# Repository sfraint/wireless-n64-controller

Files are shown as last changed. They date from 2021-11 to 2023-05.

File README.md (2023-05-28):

# wireless-n64-controller
This project and its documentation is a Work-In-Progress. I'm still working on writing everything down and working out kinks in the design files and prototypes.

**The idea is to publish the design files and software used to upgrade an OEM or cheap, wired N64 controller to a wireless, Bluetooth controller**. Hopefully these published files can assist others in completing similar projects.

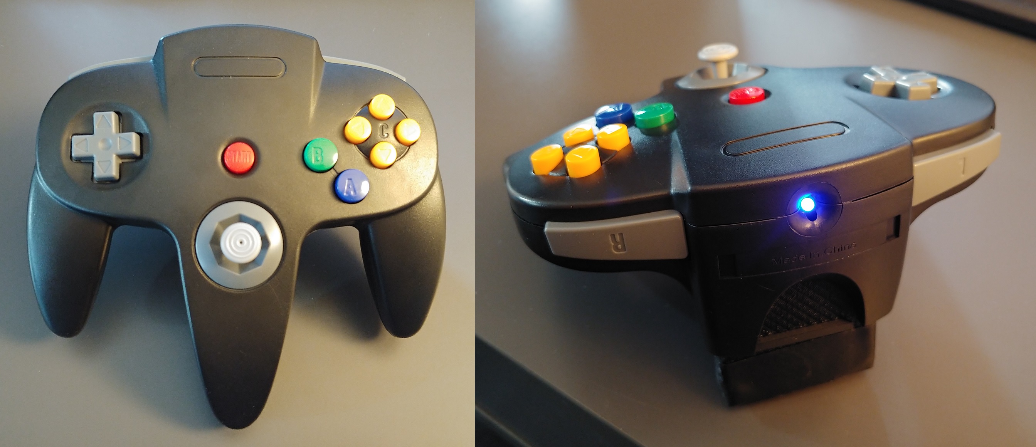
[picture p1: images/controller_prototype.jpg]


## Motivation
When this project was started, no original-form-factor bluetooth N64 wireless controllers were available for purchase. There were some two-handle controllers, inspired by N64 original controllers, but none with the original three-handle setup.

The main goal of this project was to upgrade an existing OEM or cheap three-handle N64 wired controller to use bluetooth, so it could be used with a PC and/or Raspberry Pi.

## Operation

Using the controller is pretty straightforward:

1. Insert a charged battery pak into the controller to turn it on. Note: if the LED is installed, it should light up once the controller is powered on.

2. After a few seconds, pair the controller to a client machine (e.g. phone or PC). The controller should show up as `ESP32 BLE Gamepad` in bluetooth device managers. Note: if the LED is installed, it will start blinking when the controller automatically enters pairing mode after power-up.

3. If the LED is installed, it will blink slowly when the controller is paired with a client machine.

### Analog Calibration

If you press and hold the `Start` button before the controller enters pairing mode, it will enter analog calibration mode, indicated by a rapidly blinking LED.

Upon entering calibration mode, the initial position of the joystick is recorded as the new `center` position. During calibration mode, you should rotate the joystick around in circles, reaching the all the extremes (far up, right, down, left) to reset `min` and `max` values for both the X and Y axes.

Calibration mode lasts for a few seconds (~5 sec). Upon completion, it writes results to non-volatile storage if possible, then resumes normal startup routing - entering pairing mode.

### "Soft" Buttons

This wireless N64 controller has all the normal N64 buttons plus a few extra software buttons, triggered by special button combinations. These software buttons can be associated with special functions in some emulators, like triggering the menu function, save/load state, etc.

There are currently three "soft" buttons, all triggered by pressing the center of the d-pad (i.e. pressing all 4 directions at the same time) plus either `Start`, `A`, or `B`.

## Building your own
More detailed building instructions can be found [here](building.md).

*Note: this project requires soldering and some basic understanding of electriconics and circuits. I also assume you already have soldering equipment and some ~30 gauge wire to wire up components.*

### Steps

1. Purchase the base parts. See the [BOM for more details and links](BOM.md).
   * Base N64 controller you plan to modify. I'm not sure how standardized N64 controller internals are, so it is probably a good idea to confirm the measurements of your controller match up with the spacing of the PCB mounting/securing holes.
   * ESP32 microcontroller
   * AAA terminals
   * LiPo battery
   * LiPo battery charging board

2. Print the PCB.

3. Print the battery pak pieces. Alternatively, you could skip using a battery pak and directly wire a battery to the power-in on the microcontroller.

4. Program the microcontroller.

5. Solder the microcontroller and aux boards/wires to the PCB.

6. Assemble the N64 controller.

7. Have fun! (optional)

## Debugging
**Note: make sure you disconnect the battery before plugging a USB cable into the microcontroller. If you do not do this, you could permanently damage the controller or worse, whatever is on the other end of the USB cable, e.g. your PC.**

At any point, you can remove the PCB + microcontroller from the N64 controller and monitor or reprogram the microcontroller. **TODO** add debugging details.

## Components

### Microcontroller
An [ESP32](https://en.wikipedia.org/wiki/ESP32) microcontroller is used to:

1. read the raw button presses from the button hardware in the controller

2. convert that into a USB HID report

3. send the report via Bluetooth LE to a connected client, e.g. PC

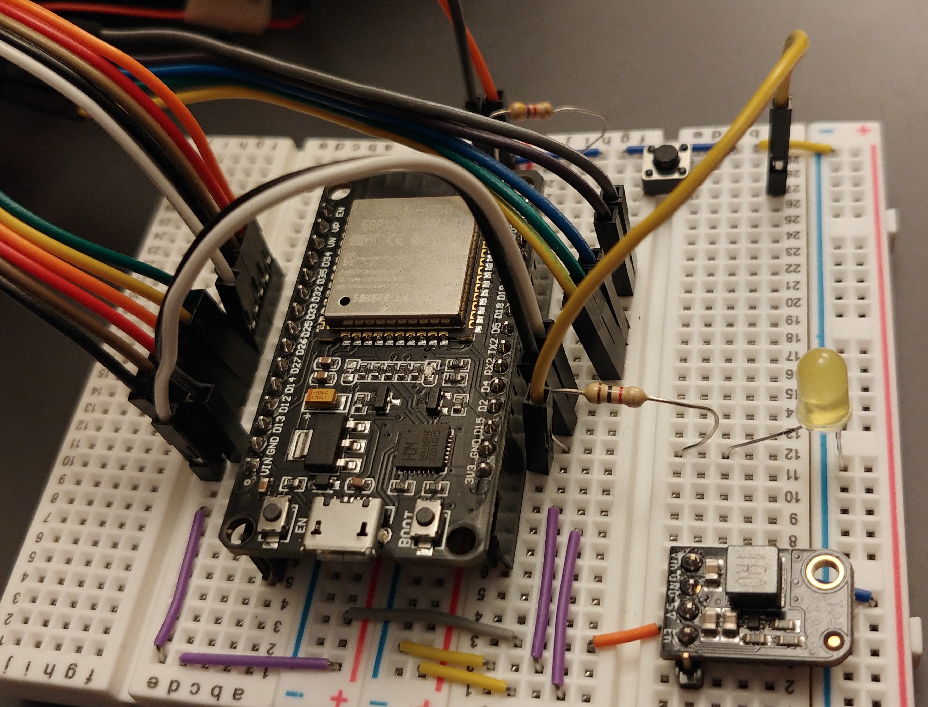
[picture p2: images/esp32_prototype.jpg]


It is also capable of a few other things like: tracking battery level, resetting Bluetooth connections, etc.

### PCB
A custom PCB was built to replace the existing controller PCB, mainly to a) make space for the ESP32 dev board I used and b) reduce the amount of soldering required.

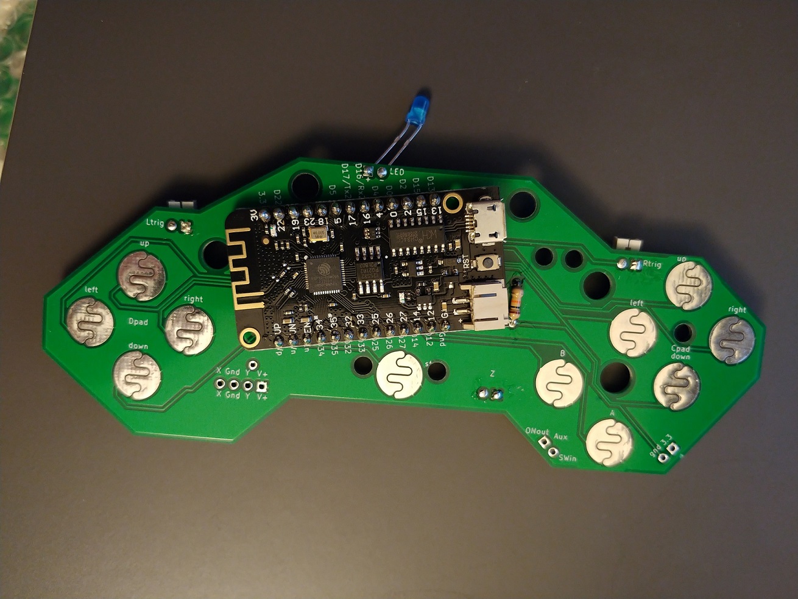
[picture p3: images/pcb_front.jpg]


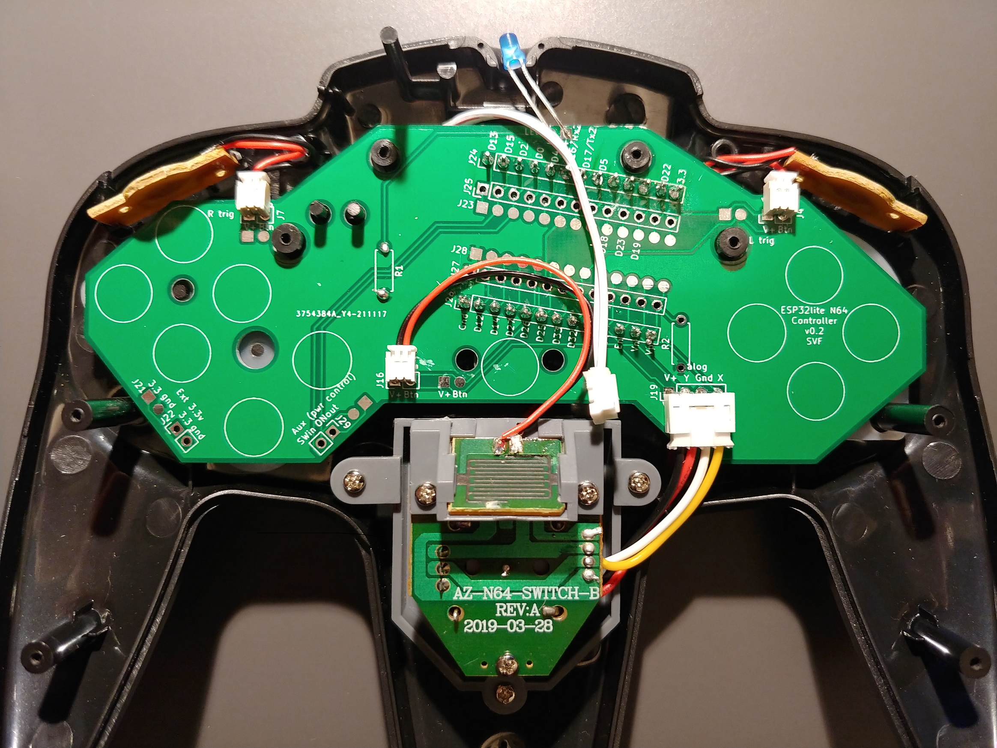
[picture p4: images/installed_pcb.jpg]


### Battery Pak
A 3d-printed battery pack that fits into the controller "pak" port was used to supply power to the controller, since it can no longer pull power from the controller cable.

This "pak" fits a small lithium polymer battery as well as charging circuitry, and connects to the controller via typical AAA spring-terminals. The "pak" was designed to fit a 6mm x 40mm x 50mm battery, but could of course fit smaller batteries with adequate padding or adhesives.

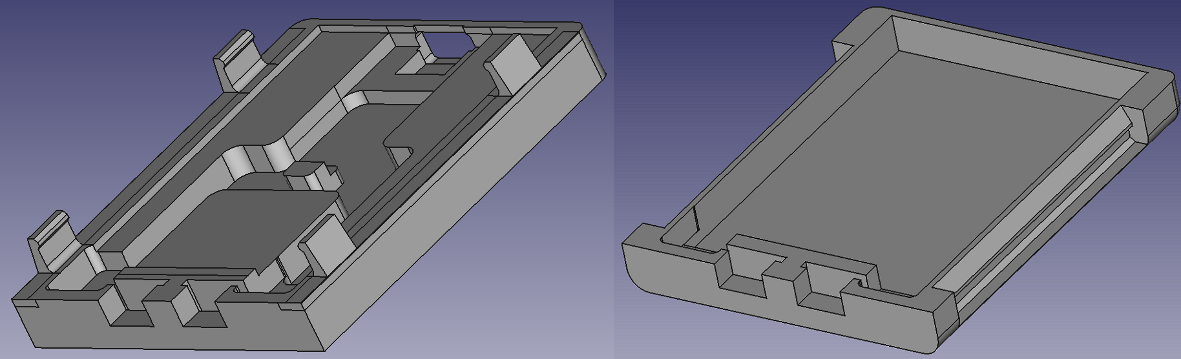
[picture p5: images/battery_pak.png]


## Performance

Rough performance numbers for the initial prototype controller are:

1. battery lifetime - using a ~1500 mAh lithium polymer battery, I expect the controller to last about ~15 hours of continuous use; I'm less sure about low-power mode lifetime, but probably a few weeks (longer if you just detach the battery).

2. controller latency - over 100 sequential button presses had a latency of between 2 and 13 ms (plus an additional ~2 ms for current software's polling interval - can reduce this using interrupts instead of polling, though chances are analog/jostick inputs will always suffer this extra latency)

   To measure approximate latency, I setup a second ESP32 which was:
   
   * a BLE client subscribed to the gamepad reports

   * running a GPIO interrupt to detect the button press

   Then, the second ESP32 recorded the time the button-interrupt was received as well as the time the BLE button-press-report was received. Got the approximate latency by subtracting the interrupt time from the BLE report time.
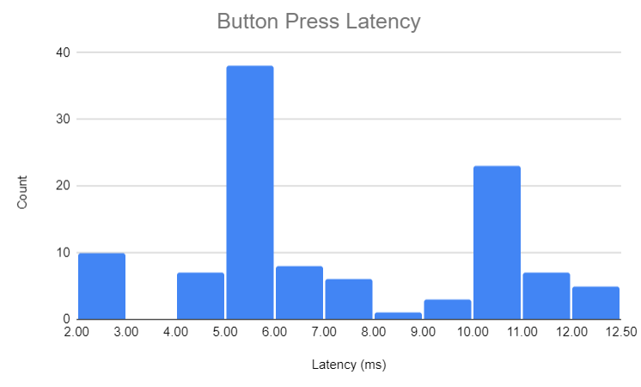
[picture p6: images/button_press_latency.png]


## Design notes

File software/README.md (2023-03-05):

## Software

This subdirectory contains source code for the software that runs on the ESP32, to track button presses and communicate with the connected bluetooth client.

Note: This uses a slightly modified version of [`ESP32-BLE-Gamepad`](https://github.com/lemmingDev/ESP32-BLE-Gamepad) which is MIT licensed, see the included copy of the BLE gamepad license in the `ESP32-BLE-Gamepad/` source directory.

### Quickstart Setup (Docker)

With docker, setting up and building this project is easy:

1. Clone this project if you haven't already: `git clone https://github.com/sfraint/wireless-n64-controller.git`

1. cd into the software directory: `cd wireless-n64-controller/software`

1. Set up NimBLE 1.3.1:

```
mkdir components
cd components
wget https://github.com/h2zero/esp-nimble-cpp/archive/refs/tags/1.3.1.zip
unzip 1.3.1.zip
```

1. Build the project: `docker run -v $PWD:/project -w /project espressif/idf:v4.4.3 idf.py build`

1. (_Note: This doesn't work on Mac_) Flash the project onto the ESP32: `docker run --rm --device=/dev/ttyUSB0 -v $PWD:/project -w /project espressif/idf:v4.4.3 idf.py -p /dev/ttyUSB0 -b 115200 flash`
   - replace `/dev/ttyUSB0` with `/dev/ttyACM0` or whatever device corresponds to your ESP32

### Regular Setup

This project requires `ESP-IDF` (works with version 4.4) and `NimBLE-cpp` (currently requires an older version, 1.3).

1. Follow the standard [ESP-IDF setup instructions](https://github.com/espressif/esp-idf)

2. Clone this project if you haven't already, e.g. `git clone https://github.com/sfraint/wireless-n64-controller.git`

3. Set up NimBLE 1.3.1

   - Create a `components` directory within the `software` directory in this project

   - Download [the NimBLE 1.3.1 source release](https://github.com/h2zero/esp-nimble-cpp/archive/refs/tags/1.3.1.zip) and extract it in the `components` directory

   - Once this is done, the `software/components/esp-nimble-cpp-1.3.1/` directory should exist in your project

#### Building and Running

Don't forget to setup env vars once per shell: `. $HOME/esp/esp-idf/export.sh`

Then, from the `software` directory in this project:

1. Build: `idf.py build`

2. Flash: `idf.py -p /dev/ttyUSB0 -b 115200 flash` (or `-p /dev/ttyACM0` or `-p COM4` or whatever port your ESP32 is connected to)

3. (Optionally) Monitor: `idf.py -p /dev/ttyUSB0 monitor` (when you're done, press `Ctrl` + `]` to end the monitor session)

#### (Optional) Re-Configuration
You shouldn't need to complete idf configuration if you're using an ESP32, as these settings are recorded in the provided `sdkconfig`. If you do need to manually configure the project, then complete the following from the `software` directory in the project:

1. Set correct target, e.g. `idf.py set-target esp32`

2. Configure project `idf.py menuconfig`

   In here, make sure to set the following settings:
   * Component config
     * Bluetooth
       * Bluetooth - `*` (enabled, required for NimBLE)
     * Bluetooth Host - `NimBLE - BLE only`
   * FreeRTOS
     * Tick rate (Hz) - `1000` (required to allow <10 ms sleep, for fast polling)

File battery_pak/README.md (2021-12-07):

## Battery Pak
This was designed with FreeCAD version 0.19.

The battery pak assembly used in this project is made up of three pieces:

1. Terminal block - this is the small piece that stays in the pak-port of the controller
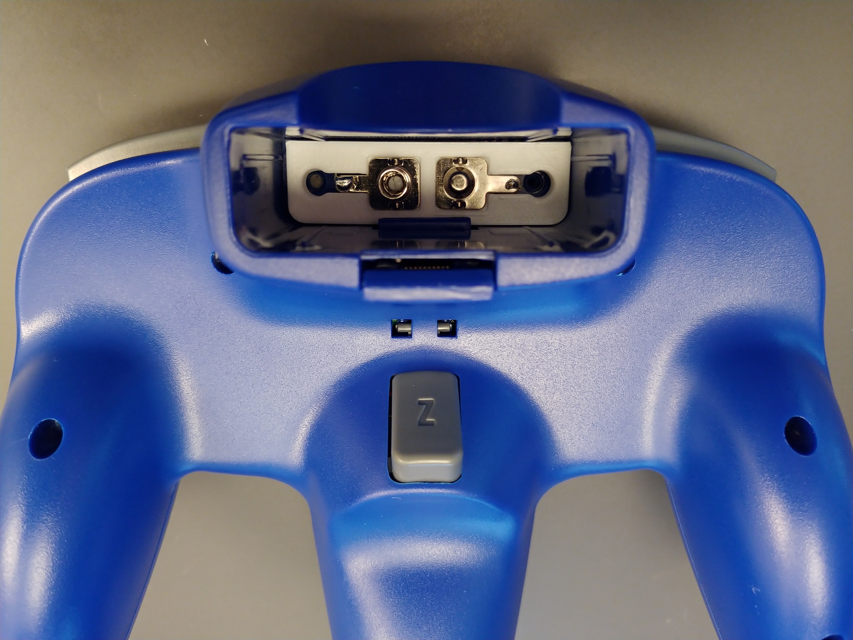
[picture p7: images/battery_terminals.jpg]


2. Pak rounded side

3. Pak square side - this side has a cutout for the micro USB charging port, charging circuitry, wiring, and terminals; it snaps together with the rounded side

The pak itself contains a lithium polymer battery, charging circuitry, and battery terminals.
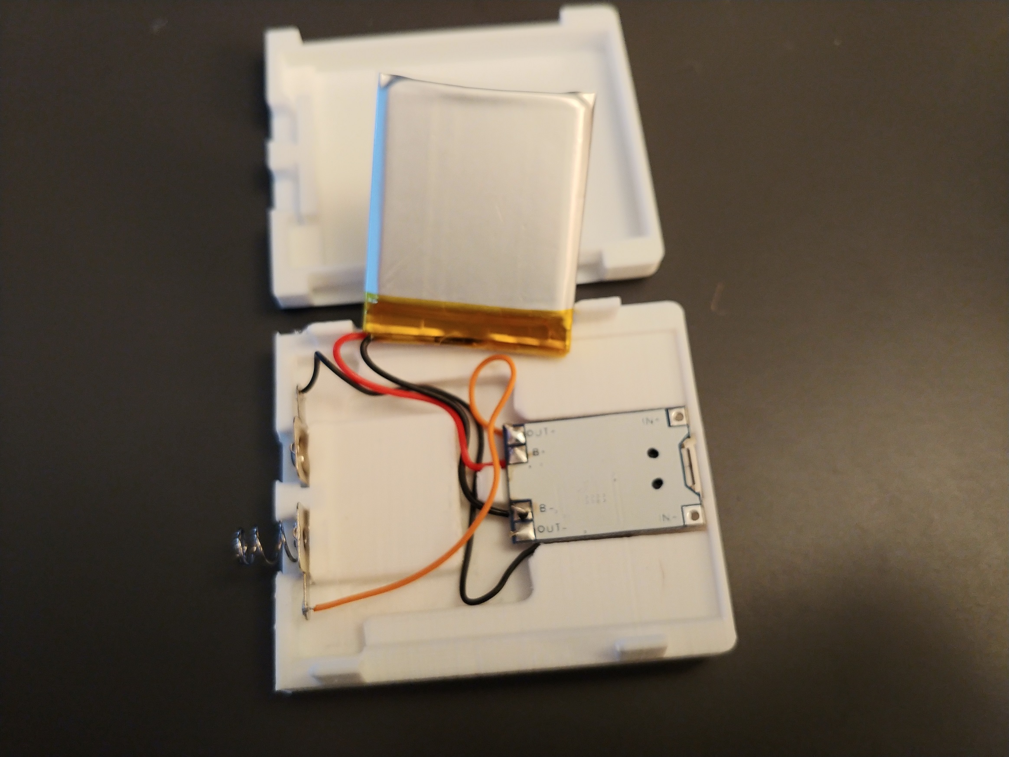
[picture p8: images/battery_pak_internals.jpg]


I've put both `.step` and `.stl` files in subdirectories here. The 3d models are also on [thingiverse](https://www.thingiverse.com/thing:5028827).

### Ordering

It is relatively cheap to print a part like this if you or a friend have a 3d printer, otherwise you're going to have to pay a shop (and likely pay for shipping), which makes the battery "pak" one of the most expensive pieces in this project.

If you do have to order from a shop, there are a lot online that will print and ship these parts for < $20.

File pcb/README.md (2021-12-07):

### PCB

This was designed with KiCad version 5.1.10

See [ordering](ordering.md) for details on ordering a PCB.

#### Front



#### Back

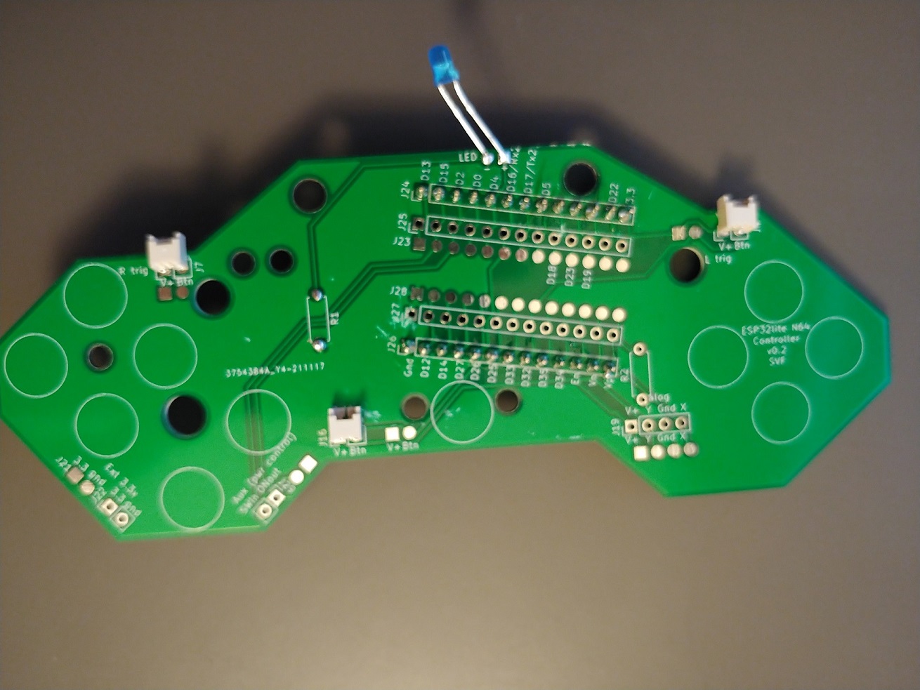
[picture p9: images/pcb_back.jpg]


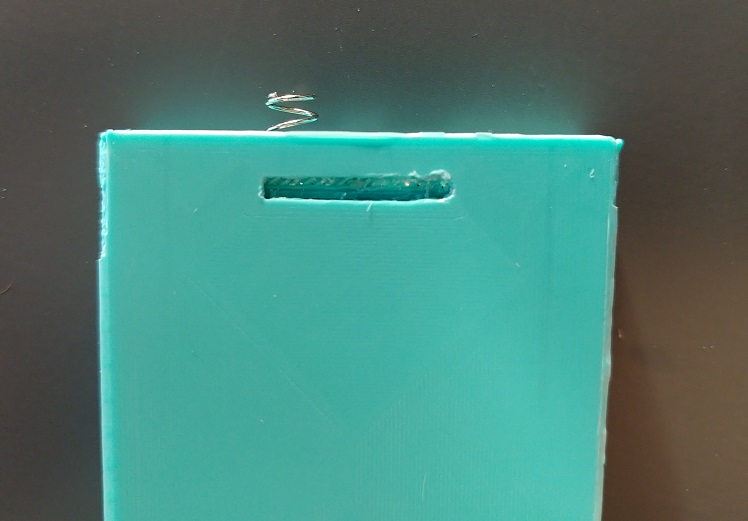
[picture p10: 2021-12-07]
images/battery_pak_terminal.jpg

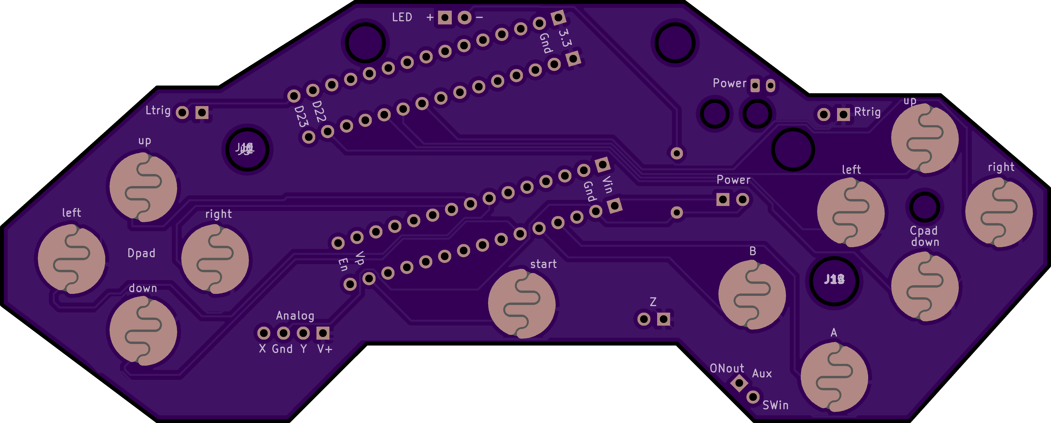
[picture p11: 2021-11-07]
images/pcb.png

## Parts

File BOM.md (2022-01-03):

# Wireless controller bill of materials
Note: as mentioned elsewhere, you *could* skip having a battery pak and wire a battery directly to the controller, but you'll still need to somehow secure the battery (e.g. electrical tape). *I also assume you already have soldering equipment and some ~30 gauge wire to wire up components.*

*Also note: the links below are just to serve as a reference. You can use equivalent items that better suit your needs, like bulk packs, cheaper or higher capacity battery, etc.*

----

**If you can print or build your own battery "pak", the total project price should be < $50 for a single controller or < $90 for 4.**

Otherwise the total price of building 1 controller is around or slightly above a similar off-the-shelf wireless controller at ~$60, but you could still produce ~4 of them for closer to $30 or $35 per controller (since many items only come in multi-packs, e.g. PCBs, battery terminals; and buying in "bulk" saves on shipping costs).

## Controller parts

Component | Quantity | Link | Price | Note
--- | --- | --- | --- | ---
N64 USB controller | 1 | [Link](https://www.amazon.com/Classic-Controller-iNNEXT-Joystick-Raspberry/dp/B0744DW55H) | $12.00 | 
--- | --- | --- | --- | ---
ESP32 Lolin32 Lite | 1 | [Link](https://www.aliexpress.com/item/4000038780903.html) | $2.67 | These are "discontinued" but I've found them readily avaialble and one of the most cost-effective uControllers for this project
Shipping | --- | --- | ~$1.50 | 
--- | --- | --- | --- | ---
PCB | 1 | [Link**](pcb/ordering.md) | ~$15 (for 5, shipped) | **See link for details
--- | --- | --- | --- | ---
**Total** | --- | --- | ~$31 | 

### Recommended parts

You can also buy JST+PH headers and cables to solder on to the boards (instead of soldering wires directly), to make the off-board connections more modular and cleaner (one set {below} is enough for several controllers).

I've also listed the `start` button pull-down resistor as recommended since I've had mixed results without it. You may need this to prevent the `start` button from getting "stuck" in the pressed position, or erroneously trigger.

Note: I've opted to use smaller headers than the board is technically designed for - this is just so hand soldering is quicker and easier. You have quite a bit of flexibility here, e.g. could try to use just PH-sized parts instead of JST parts.

Component | Quantity | Link | Price | Note
--- | --- | --- | --- | ---
PH (2.0mm) 2-pin cables | 1 | [Link](https://www.aliexpress.com/item/4001235017139.html) | $0.81 | Currently, just to connect the battery terminals to the ESP board
JST (1.25mm) 2-pin cables | 1 | [Link](https://www.aliexpress.com/item/4001235017139.html) | $0.76 | Used to connect external boards for Z, L, and R triggers
JST (1.25mm) 2-pin right angle | 1 | [Link](https://www.aliexpress.com/item/1005003115054198.html) | $0.62 | Connector for Z, L, and R triggers
PH (2.0mm) 4-pin cables | 1 | [Link](https://www.aliexpress.com/item/4001235017139.html) | $1.19 | Used to connect external analog joystick board
PH (2.0mm) 4-pin right angle | 1 | [Link](https://www.aliexpress.com/item/1005003115054198.html) | $0.66 | Connector for joystick analog inputs
Shipping | --- | --- | ~$3 | 
--- | --- | --- | --- | ---
3mm through-hole LED (5mm might also fit) | 1 | | | LED indicator for the controller - can signal when controller is on, trying to connect, etc.
10k or 20k Resistors | 2 | | | Current-limiting resistor for the LED as well as pull-down resistor for start button; smaller resistances work too, but I prefer a dimmer indicator light and lower power consumption
--- | --- | --- | --- | ---
**Total** | --- | --- | ~$10 | 

## Battery "pak" parts

*Note: if possible, you should print the `*`custom parts yourself, or have a friend with a 3d printer help.*

Component | Quantity | Link | Price | Note
--- | --- | --- | --- | ---
AAA terminals | 1 | [Link](https://www.aliexpress.com/item/32884289489.html) | ~$2.50 | May be able to find a smaller, cheaper pack - *also make sure your 3d printed controller-terminal block and battery pak will fit the terminals you order*
--- | --- | --- | --- | ---
Lithium polymer battery | 1 | [Link](https://www.aliexpress.com/item/1005003258173852.html) | $6.00 | You can also use a smaller/cheaper battery. Just make sure it fits in the 6mm x 40mm x 50mm battery pak cutout.
--- | --- | --- | --- | ---
Lithium polymer battery charging board | 1 | [Link](https://www.aliexpress.com/item/4000522397541.html) | $2.00 | 
--- | --- | --- | --- | ---
`*`Battery pak top | 1 | [Link](https://www.thingiverse.com/thing:5028827) | ~$2 | Linked "thing" is all three of the required pak parts
`*`Battery pak bottom | 1 | [Link](https://www.thingiverse.com/thing:5028827) | ~$3 | Linked "thing" is all three of the required pak parts
`*`Battery pak controller-terminal | 1 | [Link](https://www.thingiverse.com/thing:5028827) | ~$2 | Linked "thing" is all three of the required pak parts
`*`Shipping | --- | --- | ~$7 | You'll probably want to have all three pak parts 3d printed from the same supplier to save on shipping
--- | --- | --- | --- | ---
**Total** | --- | --- | ~$24.5 |

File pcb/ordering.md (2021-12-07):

## Ordering a PCB

Since this project uses a custom PCB, you'll need to order it from a PCB manufacturer.

This process is pretty simple, you just need to select a manufacturer, upload the appropriate file, and order it. In this directory I've added a `.kicad_pcb` file as well as a `gerber.zip` file, one of which should be sufficient for most PCB manufacturers.

### Manufacturers

There are a ton of manufacturers out there that will print custom PCBs. I can't really offer a comprehensive guide here for selecting a manufacturer - and I encourage you to do some research on your own.

However, I have used a couple different companies in the past, which worked out fine:

1. OSH Park - good, US-based manufacturer
  They're quick, professional, and easy-to-use, though relatively expensive for large boards like this.

2. JLCPCB - Chinese manufacturer
  I have only used them once, and things turned out fine. Much cheaper for large boards. They use lower quality materials/processes than Osh Park, but that shouldn't matter much for a project like this.

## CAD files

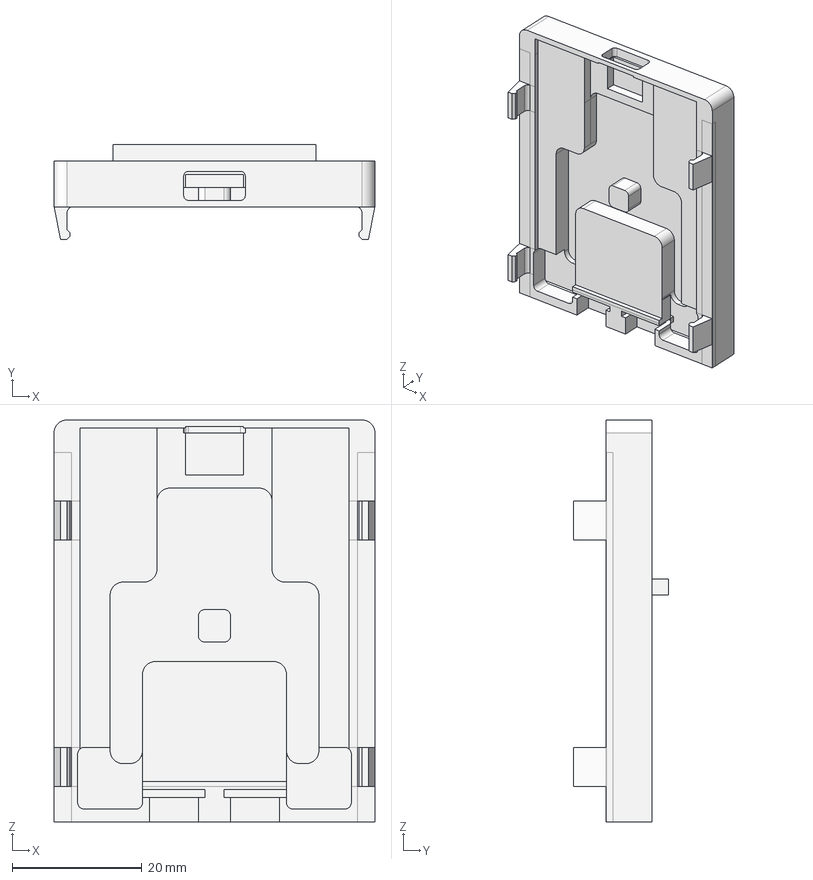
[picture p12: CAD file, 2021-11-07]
battery_pak/pak/new_rumble_pak_lipo-BodySquared.step
49.5 x 14.6 x 62.0 mm

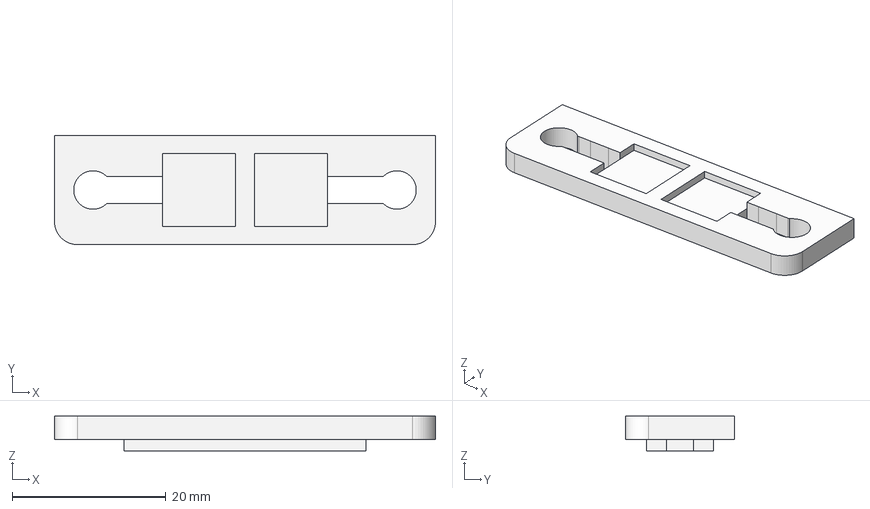
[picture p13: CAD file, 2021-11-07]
battery_pak/terminal/rumble_flat-Body.step
49.5 x 14.2 x 4.50 mm

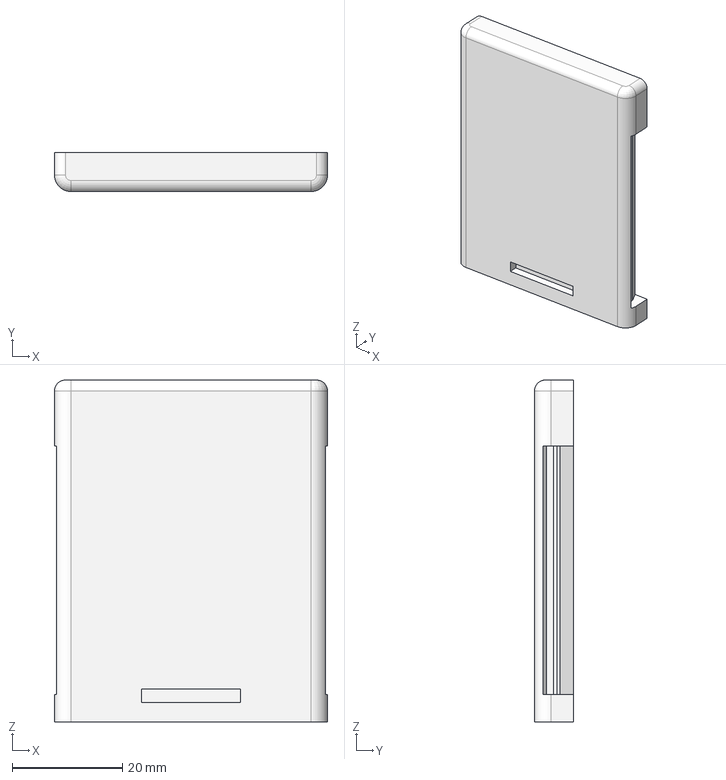
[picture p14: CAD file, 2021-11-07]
battery_pak/pak/new_rumble_pak_lipo-BodyRounded.step
49.5 x 7.10 x 62.0 mm

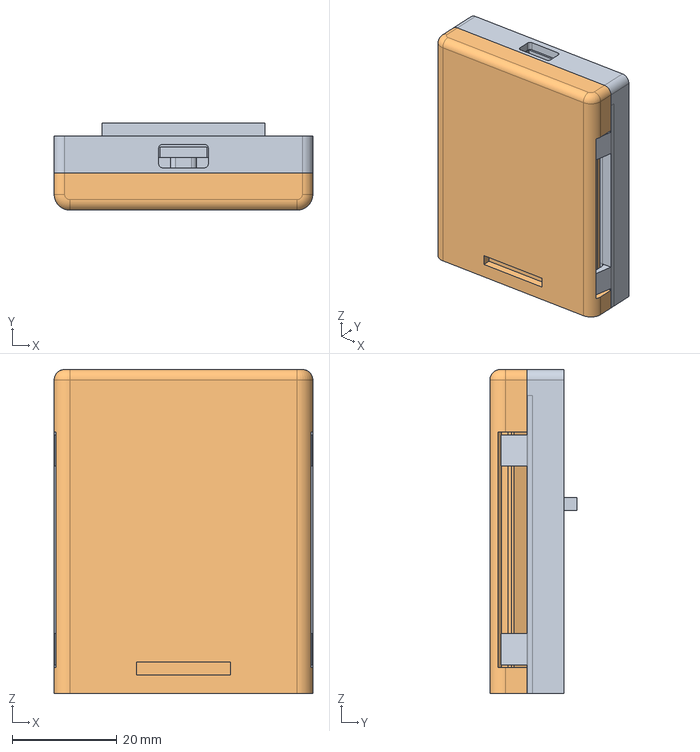
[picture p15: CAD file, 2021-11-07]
battery_pak/pak/new_rumble_pak_lipo.FCStd
49.5 x 16.7 x 62.0 mm
BodySquared
BodyRounded

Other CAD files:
battery_pak/terminal/rumble_flat.FCStd
battery_pak/pak/new_rumble_pak_lipo-BodyRounded.stl
battery_pak/pak/new_rumble_pak_lipo-BodySquared.stl
battery_pak/terminal/rumble_flat-Body.stl

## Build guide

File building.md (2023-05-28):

# Building You Own Wireless Controller

## Get the Parts

Some of the parts will take a while to manufacture and ship. For example, if you order the PCB from overseas, you might have to wait ~3 weeks for that. If you order electronic components from overseas, again you might have to wait several weeks for shipping, so plan accordingly.

### 1. Components

See the [BOM for more details and some example-component links](BOM.md), but you will need:

* Base N64 controller you plan to modify.
   * I'm not sure how standardized N64 controller internals are, so it is probably a good idea to confirm the measurements of your controller match up with the spacing of the PCB mounting/securing holes.
   * OEM controllers use a 6 pin connector compared to the cheaper alternatives which use a 4 pin. Additional steps are required to configure the software as well as modifications to the PCB for an OEM 6 pin controller.
* ESP32 microcontroller
* AAA terminals
* LiPo battery
* LiPo battery charging board
* PH/JST connectors and cables (somewhat optional - you can directly solder wires to everything instead, but I prefer removable plugs/connectors)

Optional components:

* LED
* Resistors

### 2. Print the PCB

You need to have a PCB manufacturer print out the custom PCB used in this project. The files needed to print this custom PCB are in the `pcb/` directory in this repo.

See [PCB ordering](pcb/ordering.md) for more details.

### 3. Print the battery pak pieces

You can print the battery pak pieces yourself with your (or a friend's) 3d printer and save some money, or you could have a 3d-print shop print them for you. The `.stl` (and `.step`) files for printing are in subdirectories under the `battery_pak/` directory in this repo.

See [battery pak readme](battery_pak/README.md) for more details.

Alternatively, you could skip using a battery pak and directly plug/wire a battery to the power-in on the microcontroller.

----

## Build It

### 1. Program the microcontroller

You will need to flash the software for this project on your ESP32 microcontroller. After `ESP-IDF` is setup on your PC, you can connect the microcontroller to your PC via USB and build and flash the software.

If you are using and OEM controller the software must be updated to enable SIXPIN mode before building:

```
input_poll.h - #define SIXPIN_ENABLED  1
```

See [software readme](software/README.md) for more details.

### 2. Assemble the components

Components:



1. **ESP32**: Solder the pin headers to the ESP32 and solder that to the PCB. Take care to line up the ESP32 pins correctly with the PCB labels, and note that the ESP will be on the "button" side of the PCB.

2. **Test**: At this point, I do a quick test to make sure the ESP32 is registering button presses as expected (power it up and either connect to a PC/phone with some gamepad testing application or connect the ESP32 via USB to your PC and monitor it in debug mode).

3. **2-pin headers**: Solder the 2-pin JST headers/connectors for the `R trig`, `L trig` and `Z btn`. I solder them such that the connector opening is facing upward, but either direction should work.

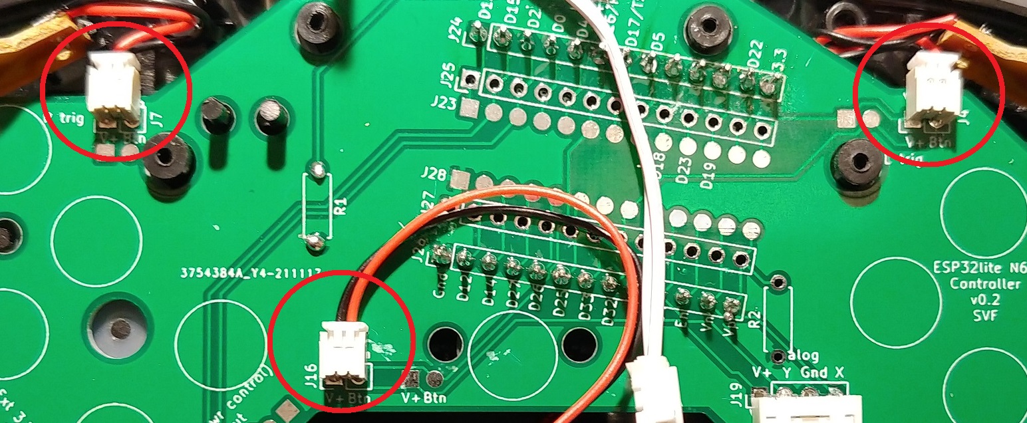
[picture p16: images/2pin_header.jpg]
   

4. **2-pin cables**: Solder one 2-pin JST cable to each external board: right trigger, left trigger, and Z board (you should cut down the length of the cable before hand so there isn't a ton of extra slack taking up space). Each board has two pads to solder to, and it doesn't matter which wire is soldered to which pad. You will need to cut or desolder the existing wires running to these boards.

5. **4-pin/6-pin header**: Solder the 4-pin PH header/connector for non OEM controllers `Analog`. I solder this so the connector opening is facing downward.

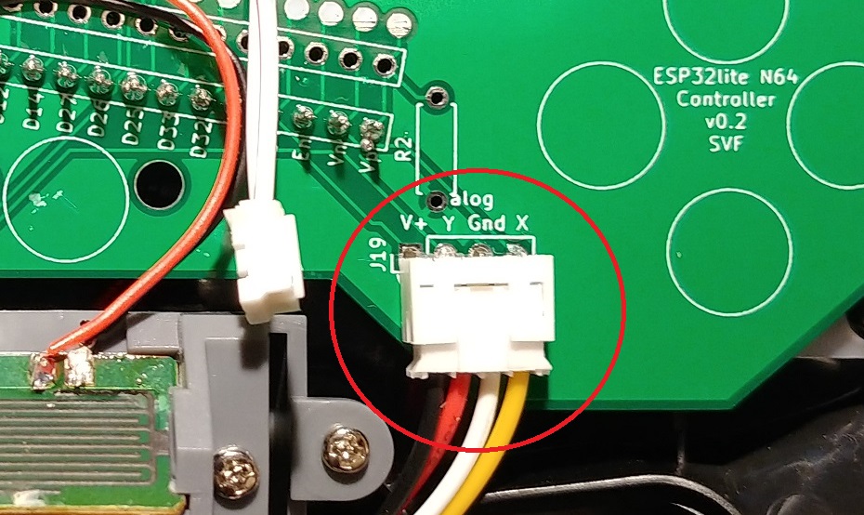
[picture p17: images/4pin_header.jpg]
   

   If using the OEM controller, the 6-pin connector needs modifying to work with the current PCB until this is updated. Carefully bend two of the pins up so the header/connector fits into the 4 pin position on the PCB. Then two additional wires are required to be soldered from these bent pins to the correct ESP32 Pins on the PCB (6 -> Pin 13,5 -> Pin 35) as per the picture below:

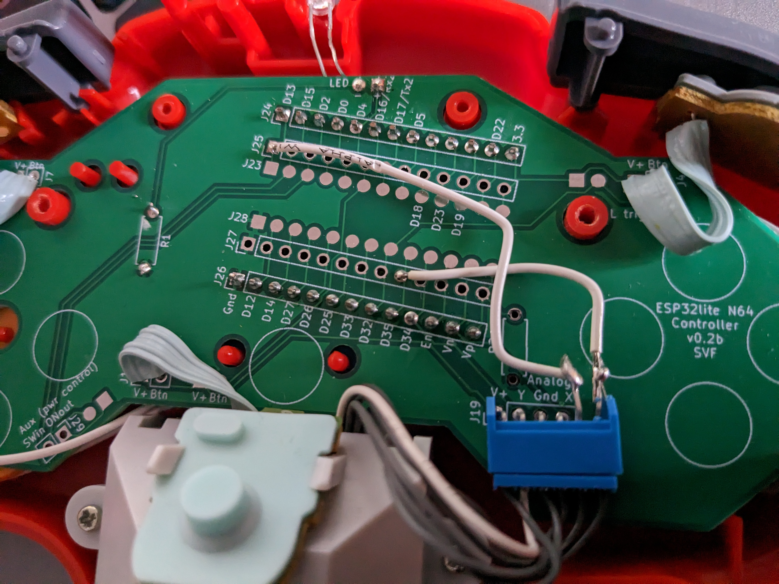
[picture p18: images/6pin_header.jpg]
   

   Additionally, for the 6 Pin connectors the wires from the joystick need swapping around in the 6pin header to match the PCB (a small screwdriver can be used to lift the holding clips and release the wires from the connector):

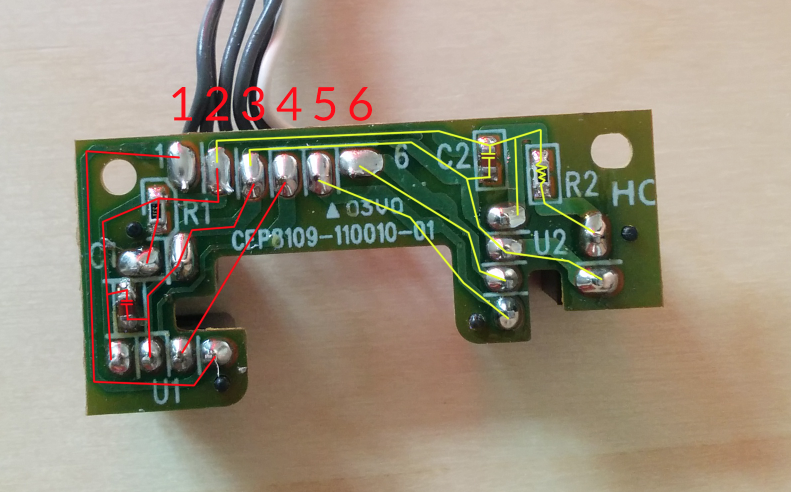
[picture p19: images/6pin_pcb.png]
   

   * Pin 1 - X
   * Pin 2 - Power 
   * Pin 3 - Ground
   * Pin 4 - XQ
   * Pin 5 - Y
   * Pin 6 - YQ

   These should be reordered to:

   * Pin 1 - power
   * Pin 2 - Y 
   * Pin 3 - Ground
   * Pin 4 - X
   * Pin 5 - XQ
   * Pin 6 - YQ
   
   (More information can be found here: https://dpedu.io/article/2015-03-11/nintendo-64-joystick-pinout-arduino)

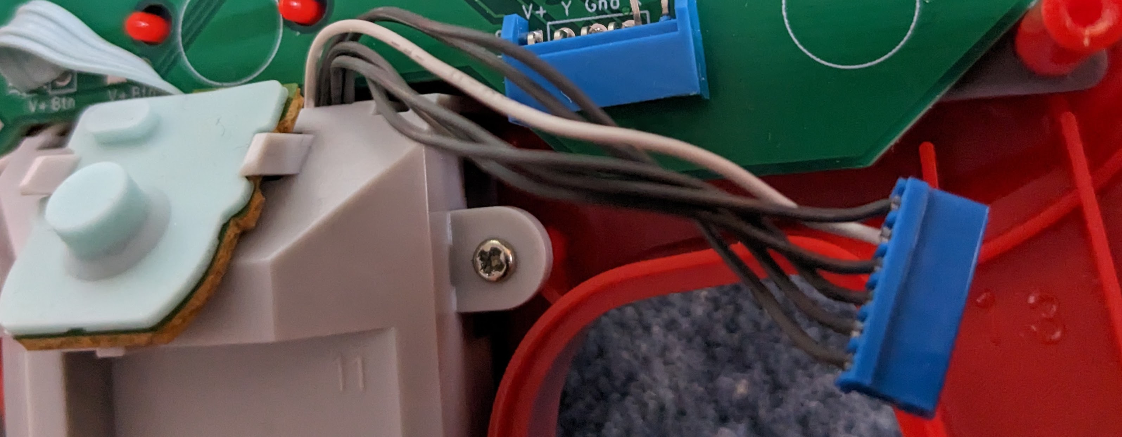
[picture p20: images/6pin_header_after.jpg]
   

6. **4-pin cables**: Solder the 4-pin PH cable to the analog joystick board (you should cut down the length of the cable before hand so there isn't a ton of extra slack taking up space). You will need to cut or desolder the existing wires running to this board - note which wires are labeled as V, X, G, and Y before removing them. Take care to solder the appropriate PH cable to the appropriate pad on the joystick board; on my board the pins were X, Gnd, Y, and V+ (from top to bottom) but yours may be different.

7. **Test**: At this point, I do another quick test to make sure the ESP32 is registering analog joystick data (same as `#2` above).

### 3. *Optional* Assembly

These steps are completely optional. You can do one or all of them if you want.

1. **LED**: Solder the LED and its current-limiting resistor (`R1`) to the PCB. This is only needed if you want visual feedback from the controller (e.g. see when it is powered up).

2. **`Start` button**: Solder the `start` button pull-down resistor (`R2`). This is only needed if you have issues with the `start` button getting "stuck" pressed or erronously registering button presses.

### 4. Assemble the battery pak

#### Battery pak

Components (ignore the fact that the charge board pictured below is a USB-C board, which doesn't fit in the current battery pak):

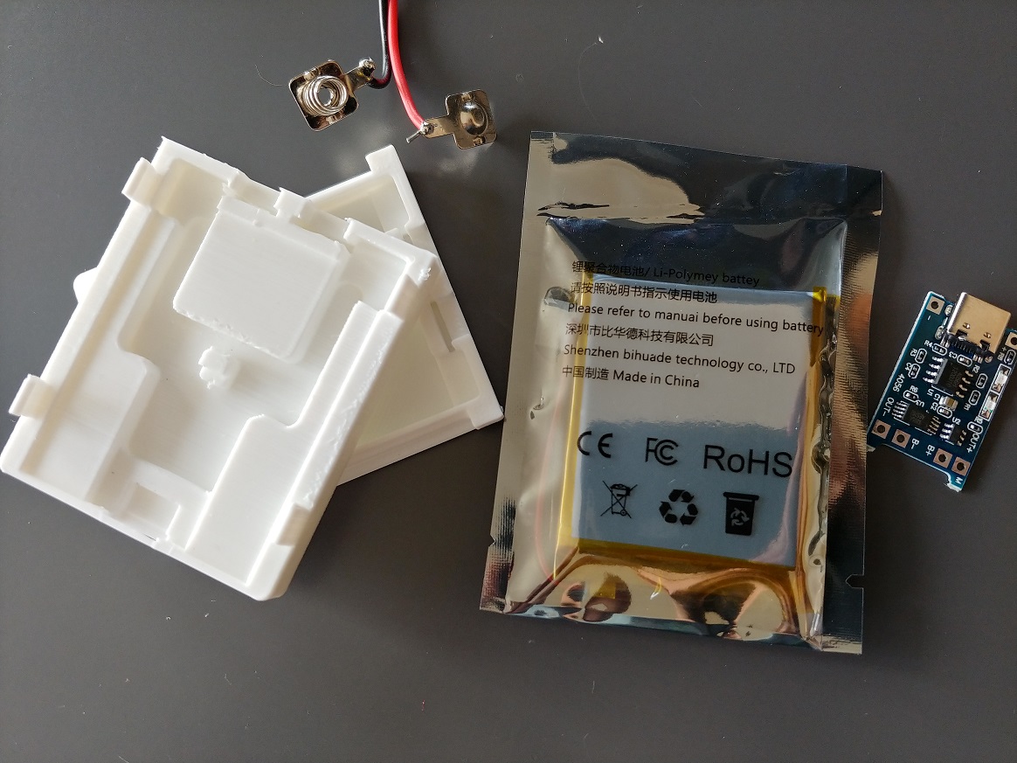
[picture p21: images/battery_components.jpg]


1. **Battery**: Solder the battery to the charging board (battery positive to `B+` and battery negative to `B-`).

2. **Terminals**: **After this step, be very careful not to let the terminals touch each other. If they touch, it will short the battery and could cause a fire. I would recommend putting electrical tape over the flat terminal for now.**

   Solder one set of the flat+spring terminals to the charging board output. Solder the flat terminal to the negative board output `OUT-` and solder the spring terminal to the positive board output `OUT+`.

3. **Assembly**: Put the charging board in the cutout in the battery pak, place the battery over that, and place the flat and spring terminals in the appropriate cutouts in the battery pak. The spring terminal should be at the top-left, when the pak-clip cutout is at the top and facing you.

   Before putting the battery over the charging board, the final assembly should look something like this:
   
   

4. (Remove electrical tap covering the flat terminal and) Clip the two pieces of the battery pak together.

#### Controller-side terminals

1. **Terminal wiring**: With one of the PH cables plugged into the ESP32, you should be able to tell which wire corresponds to `+` and which corresponds to `-` based on markings on the ESP32 board. Solder the `+` wire to another flat terminal and solder the `-` wire to another spring terminal.

2. **Assembly**: Super glue the terminals to the terminal-block piece so they line up with the opposite terminal shape from the battery pak (i.e. spring terminal should plug into flat terminal, and vice versa):

   

### 5. Reassemble the N64 controller

1. Install the PCB in the front-piece of the controller shell.

2. Plug in the external JST/PH cables into the appropriate PCB-connector.

3. Reinstall the external boards/mounts (triggers, joystick) in the appropriate spots.

   Reassembled front-piece of the controller shell should look something like this:

   

4. Install the terminal-block in the expansion-pak-port of the back-piece of the controller shell:

   

5. Mount the back-piece of the controller shell on the front-piece - make sure to reinstall the left and right trigger buttons when you do this.

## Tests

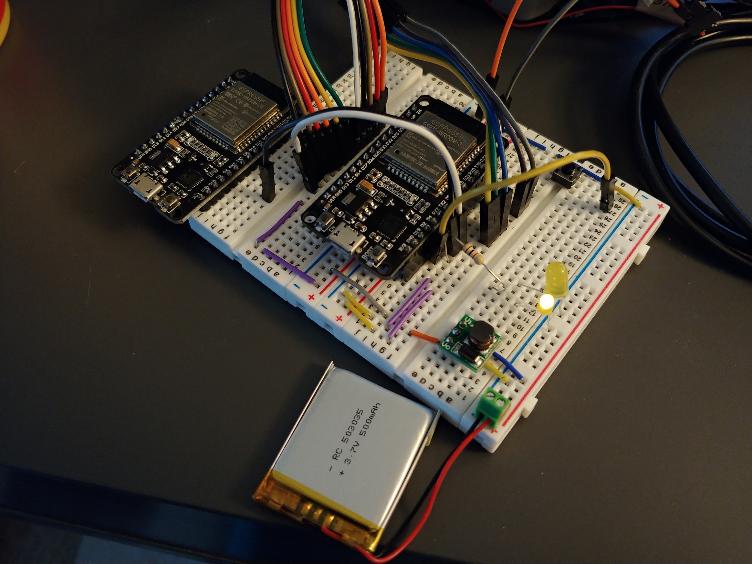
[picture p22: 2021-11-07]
images/test_setup.jpg

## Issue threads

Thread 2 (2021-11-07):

Add detailed build instructions

sfraint, 2021-11-07:
Need to:
* [x] explicitly document required ESP32 options
* [ ] try out the instructions in a new env

sfraint, 2023-05-28:
Simple (docker) and complete instructions now exist in https://github.com/sfraint/wireless-n64-controller/tree/main/software

The workflow is also [tested with GitHub actions](https://github.com/sfraint/wireless-n64-controller/blob/main/.github/workflows/software_build.yml)

Closed 2023-05-28.

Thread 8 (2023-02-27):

Support 6-pin Joystick

craigmillard86, 2023-02-27:
Hi There,

Great project! I have the PCB and ESP32 setup, but I just realised my analogue stick is a 6-pin version, not the 4pin like the board has been designed. From what I can tell the 6-pin is the standard type.

This pinout is like this https://dpedu.io/article/2015-03-11/nintendo-64-joystick-pinout-arduino

Im looking at how to modify the code to support but do you have any ideas about where to start?
get_analog_raw looks promising but not sure how to bring the other pin into it..

Thanks

sfraint, 2023-02-27:
Interesting. All of the USB controllers I've seen had 4-pin joystick cables. Does your controller have an N64 plug instead of USB? And is it an original controller or a repro?

If it is a repro, it might still use a 2-axis potentiometer which you can easily convert to 4-pin. Later this week I can try to dig up some pictures of a 6-pin to 4-pin "conversion" I did for a potentiometer based joystick.

craigmillard86, 2023-02-27:
Ah, that might be it, I am looking to convert my original OEM N64 controllers, everything else looks the same apart from the joystick. Looking to save some controllers from landfill:)

After a bit of research, the OEM 6pin sticks use two linear sensors and are not true analog as with the repro ones in the USB controllers.:
_The analog stick uses a pair of optical encoding disks to determine its relative position. This works similarly to linear encoders found in printers, except that instead of being a strip of tape/film, the N64 uses a rotating disk for each axis. Each disk has small holes along the circumference of the disk. These holes allow light to pass through to an optical sensor on the opposite side.

When the stick is moved, there are two signals generated per axis, for a total of four, which are slightly offset from each other. One of the two signals is used as the interrupt signal (XA and YA for the x-axis and y-axis respectively), and the other (XB and YB) is compared with the state of the first in order to determine which direction (positive or negative) that analog stick is moving for that axis.

To determine the direction along a particular axis and how far the stick has moved, the NUS-CNT chip will listen for any changing edge of that axis' interrupt signal (e.g. XA for the x-axis). A changing edge means any time the signal goes from LOW to HIGH, or HIGH to LOW. When an edge change is detected, the state of XA is compared against XB. If input, then the stick has moved +1 units. If input, then the stick has moved -1 units. While the analog stick reports relative movement whenever it moves, the N64 console requires the current position, not relative. In order to provide that, the NUS-CNT chip keeps track of these movements. The initial values for each axis is zero._

I am thinking something like this, y axis only here for an example (would duplicate for x axis):
```
int16_t county = 0;

int16_t analogy_to_combined_value() {
    int16_t rawa = gpio_get_level(ANALOG_Y);
    int16_t rawb = gpio_get_level(ANALOG_Yb);
  if(rawa == rawb) {
    county++;
  }
  else{
    county--;
  }
  int32_t yaxis = (county * 365); //scale by factor of 365 as n64 sensors range from -90 -> +90
  return (analog_to_joystick_value(yaxis, min_y, center_y, max_y))
}
```
This will replace the get_analog_raw function when polling for the joystick. Not sure how this will interact with analog_to_joystick_value map functions..

Any thoughts on this so far, love to get your advice on this?

sfraint, 2023-02-28:
I'll have to read up a bit more, but two things come to mind so far:
1. You're going to need 4 sensor pins from the ESP32, not just the two that are already dedicated to the joystick. And you'll need to connect these somehow since the PCB only has two traces for the joystick signals
    * Or you could add hardware to convert the encoder signal into analog signals for the ESP32, but this doesn't seem worth it in my opinion
1. Seems like you will need to use [interrupts](https://github.com/espressif/esp-idf/tree/master/examples/peripherals/gpio/generic_gpio) to detect `XA` and `YA` changes instead of monitoring this in the poll loop

craigmillard86, 2023-02-28:
Thanks! I have a test project working with interrupts and the additional Pins (13,35) via the PCB :)

I will take a look at embedding this into the project on my fork, making it optional, 4-pin or 6-pin.

craigmillard86, 2023-02-28:
First cut is on branch here:
https://github.com/craigmillard86/wireless-n64-controller/tree/6pin-n64

sfraint, 2023-03-02:
Very cool! Glad you were able to make this work!

This seems like a great feature to add back to this repo if you want to send a Pull Request 😁 That might take a little more work but hopefully it's not too bad (e.g. to update or disable calibration)

craigmillard86, 2023-03-06:
I have updated it to include Calibration, which required a refactor but all good now!

I have raised a PR [here](https://github.com/sfraint/wireless-n64-controller/pull/9) let me know your thoughts

sfraint, 2023-03-08:
Thank you! I will try to take a look and try this out this weekend

sfraint, 2023-05-28:
Support for 6-pin style joysticks was added in https://github.com/sfraint/wireless-n64-controller/pull/9

Thanks again @craigmillard86!

Closed 2023-05-28.

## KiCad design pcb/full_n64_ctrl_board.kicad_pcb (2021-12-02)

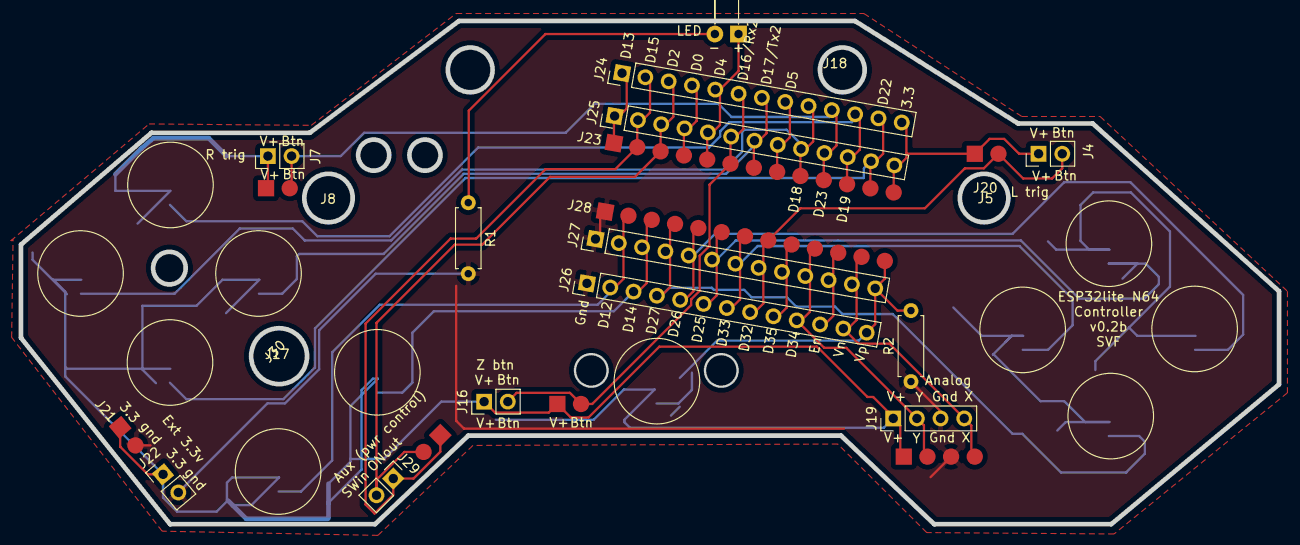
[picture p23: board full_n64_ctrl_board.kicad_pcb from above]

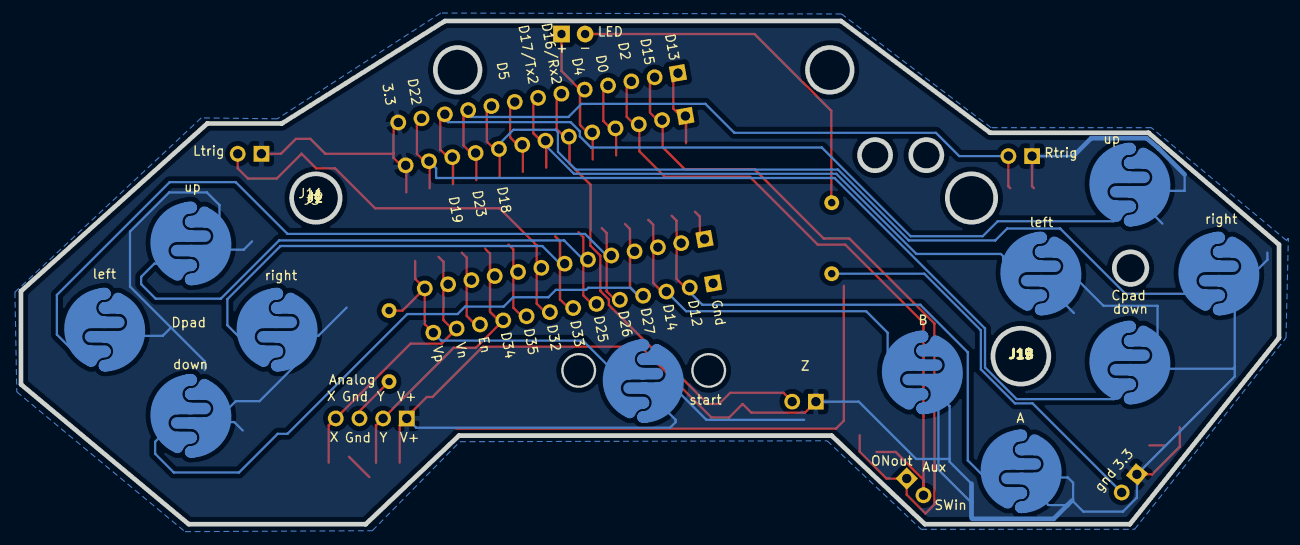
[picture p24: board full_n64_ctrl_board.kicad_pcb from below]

Board: 2 copper layers, 135.0 x 54.0 mm, 32 parts (11 on the bottom side), 27 nets.

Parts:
J1, J2, J3, J6, J9, J10, J11, J12, J13, J14, J15: Conn_01x02_Male; n64_button_pad
J4, J7, J16, J22, J29: Conn_01x02_Male; PinHeader_1x02_P2.54mm_Vertical
J5, J8, J17, J21, J30: Conn_01x02_Male; 2_pad
J18: Conn_01x02_Male; LED_D5.0mm_Horizontal_O3.81mm_Z3.0mm
J19: Conn_01x04_Male; PinHeader_1x04_P2.54mm_Vertical
J20: Conn_01x04_Male; 4_pad
J23, J28: Conn_01x13_Male; 13_pad
J24, J25, J26, J27: Conn_01x13_Male; PinHeader_1x13_P2.54mm_Vertical
R1, R2: R; R_Axial_DIN0207_L6.3mm_D2.5mm_P7.62mm_Horizontal

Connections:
GND: J19.3, J20.3, J21.2, J22.2, J26.1, J27.1, J28.1, R1.2, R2.1
unnamed: J1.2, J26.5, J27.5, J28.5
unnamed: J2.2, J26.6, J27.6, J28.6
unnamed: J10.2, J26.2, J27.2, J28.2
unnamed: J11.2, J26.13, J27.13, J28.13, R2.2
unnamed: J12.2, J23.7, J24.7, J25.7
unnamed: J13.2, J23.11, J24.11, J25.11
unnamed: J14.2, J23.12, J24.12, J25.12
unnamed: J15.2, J23.9, J24.9, J25.9
unnamed: J16.2, J17.2, J23.6, J24.6, J25.6
unnamed: J18.1, J23.5, J24.5, J25.5
unnamed: J18.2, R1.1
unnamed: J19.2, J20.2, J26.10, J27.10, J28.10
unnamed: J19.4, J20.4, J26.12, J27.12, J28.12
unnamed: J23.1, J24.1, J25.1
unnamed: J23.2, J24.2, J25.2, J29.1, J30.1
unnamed: J23.3, J24.3, J25.3, J29.2, J30.2
unnamed: J23.4, J24.4, J25.4
unnamed: J23.8, J24.8, J25.8
unnamed: J7.2, J8.2, J23.10, J24.10, J25.10
unnamed: J9.2, J26.3, J27.3, J28.3
unnamed: J3.2, J26.4, J27.4, J28.4
unnamed: J6.2, J26.7, J27.7, J28.7
unnamed: J4.2, J5.2, J26.8, J27.8, J28.8
unnamed: J26.9, J27.9, J28.9
unnamed: J26.11, J27.11, J28.11
VCC: J1.1, J2.1, J3.1, J4.1, J5.1, J6.1, J7.1, J8.1, J9.1, J10.1, J11.1, J12.1, J13.1, J14.1, J15.1, J16.1, J17.1, J19.1, J20.1, J21.1, J22.1, J23.13, J24.13, J25.13

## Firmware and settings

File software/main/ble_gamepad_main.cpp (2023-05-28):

#include "ESP32-BLE-Gamepad/BleGamepad.h"
#include "ble_gamepad_main.h"
#include "input_poll.h"
#include "storage.h"

#include <stdio.h>
#include <sys/time.h>

#include "sdkconfig.h"
#include "freertos/FreeRTOS.h"
#include "freertos/task.h"
#include "freertos/queue.h"
#include "esp_system.h"
#include "esp_spi_flash.h"
#include "driver/adc.h"
#include "driver/gpio.h"

// LED mode and misc related status indicators
uint32_t led_mode = 0;
bool bt_connected = false;
// Controller state-machine
#define STATE_STARTUP      0
#define STATE_CALIBRATION  1
#define STATE_RUNNING      2

uint32_t current_state = STATE_STARTUP;
bool startup_routine_running = true;

BleGamepad bleGamepad;
xQueueHandle gpio_evt_queue = NULL; // Button-press event queue
// For 6-pin joysticks: count movement when an edge change is detected
int countx = 0;
int county = 0;
// For 6-pin joysticks: X Interrupt Hook 
static void IRAM_ATTR gpiox_isr_handler(void* arg)
{
    uint32_t gpio_num = (uint32_t) arg;
    if(gpio_get_level((gpio_num_t) SIXPIN_ANALOG_X) == gpio_get_level((gpio_num_t) SIXPIN_ANALOG_XQ)){ 
                        countx++;
                    }
                    else{
                        countx--;
                    }    
                     
}
// For 6-pin joysticks: Y Interrupt Hook
static void IRAM_ATTR gpioy_isr_handler(void* arg)
{
       uint32_t gpio_num = (uint32_t) arg;
    if(gpio_get_level((gpio_num_t) SIXPIN_ANALOG_Y) == gpio_get_level((gpio_num_t) SIXPIN_ANALOG_YQ)){ 
                        county--;
                    }
                    else{
                        county++;
                    } 
}

// Setup specified pin number as pulled-down, input pin
void setup_input_pin(uint32_t pin) {
    gpio_config_t io_conf;
    io_conf.intr_type = GPIO_INTR_DISABLE;
    io_conf.mode = GPIO_MODE_INPUT;
    io_conf.pin_bit_mask = ((1ULL << pin));
    io_conf.pull_down_en = (gpio_pulldown_t) 1;
    io_conf.pull_up_en = (gpio_pullup_t) 0;
    gpio_config(&io_conf);
}

// Setup GPIO
void setup_gpio()
{
    // Standard gamepad buttons
    for (uint32_t i = 0 ; i < NUM_OF_BUTTONS ; i++)
    {
        setup_input_pin(buttonPins[i]);
        previousButtonStates[i] = 0;
        currentButtonStates[i] =  0;
    }
    // D-pad
    for (uint32_t i = 0; i < 4; i++) {
        setup_input_pin(dpadPins[i]);
        previousDpadStates[i] = 0;
        currentDpadStates[i] =  0;
    }

    // Battery Monitor, Pin also used with 6 pin Joystick, therefore only availble with 4 pin joysticks
    if(!SIXPIN_ENABLED){
    adc1_config_width(ADC_WIDTH_BIT_12);
    adc1_config_channel_atten(ANALOG_BAT, ADC_ATTEN_DB_11);
    }   

    // For 6-pin joysticks: Joystick setup
    if(SIXPIN_ENABLED){
        //zero-initialize the config structure.
        gpio_config_t io_conf = {};
        //disable pull-down mode
        io_conf.pull_down_en = (gpio_pulldown_t) 0;
        //interrupt of any edge
        io_conf.intr_type = GPIO_INTR_ANYEDGE;
        //bit mask of the pins
        io_conf.pin_bit_mask = GPIO_INPUT_PIN_SEL;
        //set as input mode
        io_conf.mode = GPIO_MODE_INPUT;
        //disable pull-up mode
        io_conf.pull_up_en = (gpio_pullup_t) 0;
        gpio_config(&io_conf);
        
        //SIXPIN Joystick Interrupts and Handler setup
        //install gpio isr service
        gpio_install_isr_service(ESP_INTR_FLAG_DEFAULT);
        //hook isr handler for specific gpio pin
        gpio_isr_handler_add((gpio_num_t) SIXPIN_ANALOG_X, gpiox_isr_handler, (void*) SIXPIN_ANALOG_X);
        //hook isr handler for specific gpio pin
        gpio_isr_handler_add((gpio_num_t) SIXPIN_ANALOG_Y, gpioy_isr_handler, (void*) SIXPIN_ANALOG_Y);

        //Adjust max ADC reading for SIXPIN joystick potentiometers
        max_x = SIXPIN_ANALOG_MAX; 
        max_y = SIXPIN_ANALOG_MAX;
        center_x = SIXPIN_ANALOG_CENTER;
        center_y = SIXPIN_ANALOG_CENTER;
    }
    else{
    adc1_config_channel_atten(ANALOG_X, ADC_ATTEN_DB_11);
    adc1_config_channel_atten(ANALOG_Y, ADC_ATTEN_DB_11);
    }
    // Other IO
    gpio_config_t io_conf;
    // Button feedback LED output
    io_conf.intr_type = GPIO_INTR_DISABLE;
    io_conf.mode = GPIO_MODE_OUTPUT;
    io_conf.pin_bit_mask = ((1ULL << LED_IO_PIN));
    io_conf.pull_down_en = (gpio_pulldown_t) 0;
    io_conf.pull_up_en = (gpio_pullup_t) 0;
    gpio_config(&io_conf);
    // Management button
    io_conf.intr_type = GPIO_INTR_DISABLE;
    io_conf.mode = GPIO_MODE_INPUT;
    io_conf.pin_bit_mask = ((1ULL << MGMT_IO_PIN));
    io_conf.pull_down_en = (gpio_pulldown_t) 0;
    io_conf.pull_up_en = (gpio_pullup_t) 0;
    gpio_config(&io_conf);
}

void setup_bt() {
    uint32_t count = NUM_OF_BUTTONS + NUM_OF_SOFT_BUTTONS;
    uint32_t hat_count = 0;
    if (ENABLE_HAT_DPAD) {
        hat_count = 2;
    }
    printf("Setting up BT controller w/ %d buttons (hat dpad %d, hat count %d)", count, ENABLE_HAT_DPAD, hat_count);
    bleGamepad.begin(count, hat_count, true, true, false, false, false, false, false, false, false, false, false, false, false);
    bleGamepad.setAutoReport(false);
}


static void led_toggle_helper(uint32_t val) {
    gpio_set_level((gpio_num_t) LED_IO_PIN, val);
}


// Control LED output
static void led_handler(void* arg)
{
    const TickType_t xDelay = 50 / portTICK_PERIOD_MS;  // 50ms
    uint32_t count = 0;
    for(;;) {
        const uint32_t on = 1;
        const uint32_t off = 0;
        uint32_t very_slow = (count % 32) == 1;
        uint32_t slow = (count % 16) == 1;
        uint32_t medium = (count % 8) == 1;
        uint32_t fast = (count % 4) == 1;
        uint32_t very_fast = (count % 2) == 1;
        bt_connected = bleGamepad.isConnected();
        if (current_state == STATE_STARTUP) {
            // Starting up
            led_toggle_helper(on);
        } else if (current_state == STATE_CALIBRATION) {
            led_toggle_helper(very_fast);
        } else if (!bt_connected) {
            // Waiting for BT connection
            led_toggle_helper(medium);
        } else {
            // Connected, running like normal
            led_toggle_helper(very_slow);
        }
        // TODO re-incorporate or remove `led_mode`
        /*} else if (led_mode == LED_OFF) {
            led_toggle_helper(off);
        } else if (led_mode == LED_ON) {
            led_toggle_helper(on);
        } else if (led_mode == LED_BLINK_SLOW) {
            led_toggle_helper(slow);
        } else if (led_mode == LED_BLINK_MED) {
            led_toggle_helper(medium);
        } else if (led_mode == LED_BLINK_FAST) {
            led_toggle_helper(fast);
        } else if (led_mode == LED_BLINK_VERY_FAST) {
            led_toggle_helper(very_fast);
        }*/
        vTaskDelay(xDelay);
        count += 1;
        if (count > 31) count = 0;
    }
}


// Handle button press events
static void gpio_button_handler(void* arg)
{
    const TickType_t xDelay = 500 / portTICK_PERIOD_MS;  // 500ms
    uint32_t button_press_event;
    uint32_t last_event = NONE;
    //gpio_set_level((gpio_num_t) GPIO_OUTPUT_IO_1, 1);
    for(;;) {
        if(xQueueReceive(gpio_evt_queue, &button_press_event, portMAX_DELAY)) {

            // Button UP events
            if (button_press_event == BUTTON_UNPRESS) {
                printf("    (unpress received after %d)\n", last_event);
                //gpio_set_level((gpio_num_t) GPIO_OUTPUT_IO_0, 0);
                
                // Shutdown
                // https://randomnerdtutorials.com/esp32-external-wake-up-deep-sleep/
                // https://docs.espressif.com/projects/esp-idf/en/latest/esp32/api-reference/system/sleep_modes.html
                // https://github.com/espressif/esp-idf/blob/master/examples/system/deep_sleep/main/deep_sleep_example_main.c
                if (last_event == BUTTON_VERY_LONG_PRESS) {
                    // This is where you could do a shutdown procedure, e.g.
                    //esp_sleep_enable_ext0_wakeup(GPIO_NUM_2, 1); //1 = High, 0 = Low
                    //esp_deep_sleep_start();
                }
                continue;
            }

            // Button DOWN events
            if (button_press_event == BUTTON_PRESS) {
                printf("    (press received)\n");
            } else if (button_press_event == BUTTON_LONG_PRESS) {
                printf("    (long press received)\n");            
            } else if (button_press_event == BUTTON_VERY_LONG_PRESS) {
                printf("    (very long press received)\n");
            }
            last_event = button_press_event;
        }
    }
}

void setup_tasks()
{
    gpio_evt_queue = xQueueCreate(10, sizeof(uint32_t));
    xTaskCreate(gpio_button_handler, "gpio_button_handler", 2048, NULL, 10, NULL);
    xTaskCreate(led_handler, "led_handler", 2048, NULL, 10, NULL);
}

void setup_poll_task()
{
    xTaskCreate(input_poll_loop, "in_poll", 4096, NULL, 10, NULL);
}


extern "C" {
   void app_main();
}


// Calibrate analog X-Y inputs and optionally write to persistent storage. Uses initial values as "centered", then monitors min and max values for ~10 seconds to determine range. 
void calibrate(bool write_to_storage) {
    const TickType_t xDelay = 10 / portTICK_PERIOD_MS;  // 10ms

    if (SIXPIN_ENABLED){center_x = 0;} else{center_x = get_analog_raw(ANALOG_X);};
    min_x = center_x;
    max_x = center_x;

    if (SIXPIN_ENABLED){center_y = 0;} else{center_y = get_analog_raw(ANALOG_Y);};
    min_y = center_y;
    max_y = center_y;

    // Read extreme values for ~10 seconds
    for (int i = 0; i < 1000; i++) {
        int32_t  x;
        if (SIXPIN_ENABLED) {x = countx;} else{x = get_analog_raw(ANALOG_X);};
        
        if (x < min_x) min_x = x;
        if (x > max_x) max_x = x;

        int32_t  y;
        if (SIXPIN_ENABLED) {y = county;} else{y = get_analog_raw(ANALOG_Y);};
       
        if (y < min_y) min_y = y;
        if (y > max_y) max_y = y;

        vTaskDelay(xDelay);
    }

    printf("Calibration results:\n");
    printf("X (left, center, right): %d, %d, %d\n", min_x, center_x, max_x);
    printf("Y (up, center, down):    %d, %d, %d\n", min_y, center_y, max_y);
    if (write_to_storage) {
        write_storage_values(STORAGE_KEY_X_CENTER, center_x, STORAGE_KEY_X_MIN, min_x, STORAGE_KEY_X_MAX, max_x);
        write_storage_values(STORAGE_KEY_Y_CENTER, center_y, STORAGE_KEY_Y_MIN, min_y, STORAGE_KEY_Y_MAX, max_y);
        printf("Calibration data written to storage\n");
    }
}


void app_main(void)
{
    startup_routine_running = true;
    current_state = STATE_STARTUP;
    led_mode = LED_ON;
    bool storage_ok = init_storage();
    setup_gpio();
    setup_tasks();
    setup_bt();
    const TickType_t xDelay = 1000 / portTICK_PERIOD_MS;  // 1s
    vTaskDelay(xDelay);
    
    // Get initial button state to enter special modes
    poll_buttons();

    // Enter calibration mode if `START` is being pressed
    if (currentButtonStates[6]) {
        current_state = STATE_CALIBRATION;
        printf("Starting calibration\n");
        calibrate(storage_ok);
    } else {
        printf("Skipping calibration\n");
    }

    if (storage_ok) {
        center_x = read_storage_value(STORAGE_KEY_X_CENTER, ANALOG_CENTER);
        min_x = read_storage_value(STORAGE_KEY_X_MIN, ANALOG_MIN);
        max_x = read_storage_value(STORAGE_KEY_X_MAX, ANALOG_MAX);
        center_y = read_storage_value(STORAGE_KEY_Y_CENTER, ANALOG_CENTER);
        min_y = read_storage_value(STORAGE_KEY_Y_MIN, ANALOG_MIN);
        max_y = read_storage_value(STORAGE_KEY_Y_MAX, ANALOG_MAX);
        printf("Read joystick calibration values:\n");
        printf("    X: %d, %d, %d\n", min_x, center_x, max_x);
        printf("    Y: %d, %d, %d\n", min_y, center_y, max_y);
    }

    printf("Initial setup complete!\n");
    
    startup_routine_running = false;
    current_state = STATE_RUNNING;
    setup_poll_task();

    /* Print chip information */
    esp_chip_info_t chip_info;
    esp_chip_info(&chip_info);
    printf("This is %s chip with %d CPU core(s), WiFi%s%s, ",
            CONFIG_IDF_TARGET,
            chip_info.cores,
            (chip_info.features & CHIP_FEATURE_BT) ? "/BT" : "",
            (chip_info.features & CHIP_FEATURE_BLE) ? "/BLE" : "");

    printf("silicon revision %d, ", chip_info.revision);

    printf("%dMB %s flash\n", spi_flash_get_chip_size() / (1024 * 1024),
            (chip_info.features & CHIP_FEATURE_EMB_FLASH) ? "embedded" : "external");

    printf("Minimum free heap size: %d bytes\n", esp_get_minimum_free_heap_size());
}

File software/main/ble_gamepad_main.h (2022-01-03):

#ifndef BLE_GAMEPAD_MAIN_H
#define BLE_GAMEPAD_MAIN_H

#include "ESP32-BLE-Gamepad/BleGamepad.h"
#include "freertos/queue.h"

// CPU core number for compute loads
#define COMPUTE_CORE         1

// LED state
extern uint32_t led_mode;
#define LED_IO_PIN             4
// LED command events
#define LED_OFF                0
#define LED_ON                 1
#define LED_BLINK_SLOW         2
#define LED_BLINK_MED          3
#define LED_BLINK_FAST         4
#define LED_BLINK_VERY_FAST    5

// Non-volatile Storage keys
#define STORAGE_KEY_X_MIN      "min_x"
#define STORAGE_KEY_X_CENTER   "center_x"
#define STORAGE_KEY_X_MAX      "max_x"
#define STORAGE_KEY_Y_MIN      "min_y"
#define STORAGE_KEY_Y_CENTER   "center_y"
#define STORAGE_KEY_Y_MAX      "max_y"

extern BleGamepad bleGamepad;

extern xQueueHandle gpio_evt_queue; // Button-press event queue

#endif

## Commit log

2021-11-07 initial skeleton
    [full_n64_ctrl_board.kicad_pcb, new_rumble_pak_lipo-BodyRounded.step, new_rumble_pak_lipo-BodyRounded.stl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]
2021-11-13 larger stack for input poll loop, more analog sensitivity, debug printing
2021-11-20 cleanup/clarify button mapping
2021-11-22 add soft buttons
2021-11-23 add battery level logic, reset debug flag
    [ble_gamepad_main.cpp, input_poll.cpp, input_poll.h]
2021-11-24 update files
    [full_n64_ctrl_board.kicad_pcb]
2021-11-25 update installed PCB image
2021-11-26 fix pin mapping and conflicts
    [ble_gamepad_main.cpp, input_poll.h]
2021-12-02 update PCB, update button mapping, re-enable battery level setup
    [full_n64_ctrl_board.kicad_pcb]
2021-12-07 Lite-board detailed building instructions (#5)
    * BOM and readme simplifications
    * update images
    * more detailed build instructions
2021-12-26 switch to more debug statements
2021-12-27 update LED indicator behavior; solid startup, flash waiting for BT, slow flash when connected
2022-01-03 calibration with persistent storage, use calibration values in analog polling
2022-01-03 Optional -> Recommended parts
    Make optional parts recommended instead. Note: I've now had some issues with the `start` button after extended use on one of the prototype controllers (registering erroneous button presses occasionally - maybe ~once per minute during active gameplay).
2022-01-16 Add Operation details
    Add details about Operation, Analog calibration, "Soft" buttons
2022-09-03 CI: add workflow to build ESP32 software project (#6)
    add software build workflow
